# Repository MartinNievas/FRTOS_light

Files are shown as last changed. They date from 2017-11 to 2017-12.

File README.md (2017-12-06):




# Linterna frontal con diferentes modos de iluminación
La linterna cuenta con diferentes modos de iluminación. Es una versión simplificada inspirada en el modelo 
[NAO&reg;](https://www.petzl.com/US/en/Sport/PERFORMANCE-headlamps/NAO) de Petzl&reg;

## Modos de iluminación
* OFF (Default)
* ADAPTABLE
* AMPLIO
* CENTRADO
* AMPLIO + CENTRADO

##### Modo ADAPTABLE
La linterna regula la intensidad de los LED basada en la medición realizada por un fotodiodo. Los umbrales de cambio 
de intensidad controlan una máquina de estados, para evitar oscilaciones al cambiar entre modos.

## Circuito
La linterna se controla mediante una Arduino Pro-Mini y dos mosfet SMD (si2302) para controlar los LED. Cuenta con un botón en la placa 
para ir cambiando entre modos. 

## Alimentación
Utiliza dos bateras 18650 en serie. Esto  es así para alimentar la Arduino mediante el regulador provisto en la placa. 

## LEDs
La linterna utiliza dos LED. Uno de 3W para la iluminación centrada con un colimador de 16°, y un led de 5W para 
la iluminación amplia con un difusor de 60°

## Compilación y carga
El proyecto utiliza [platformio](http://platformio.org/). Para compilar y cargar en la Arduino hacer:
```
platofrmio run -t upload
```

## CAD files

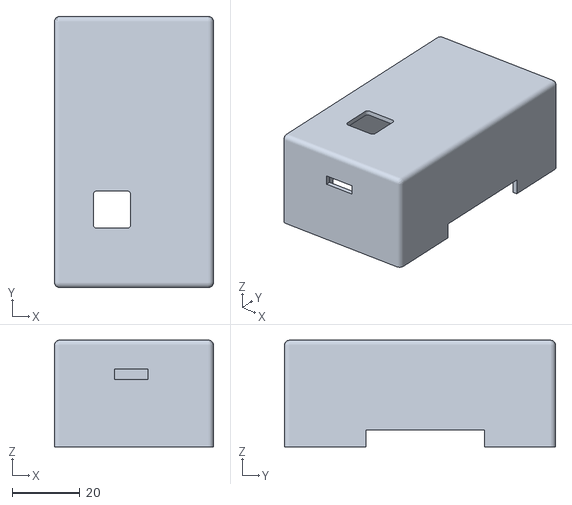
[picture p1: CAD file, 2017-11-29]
carcasa/tapa_porta_baterias.stl
47.0 x 80.0 x 31.5

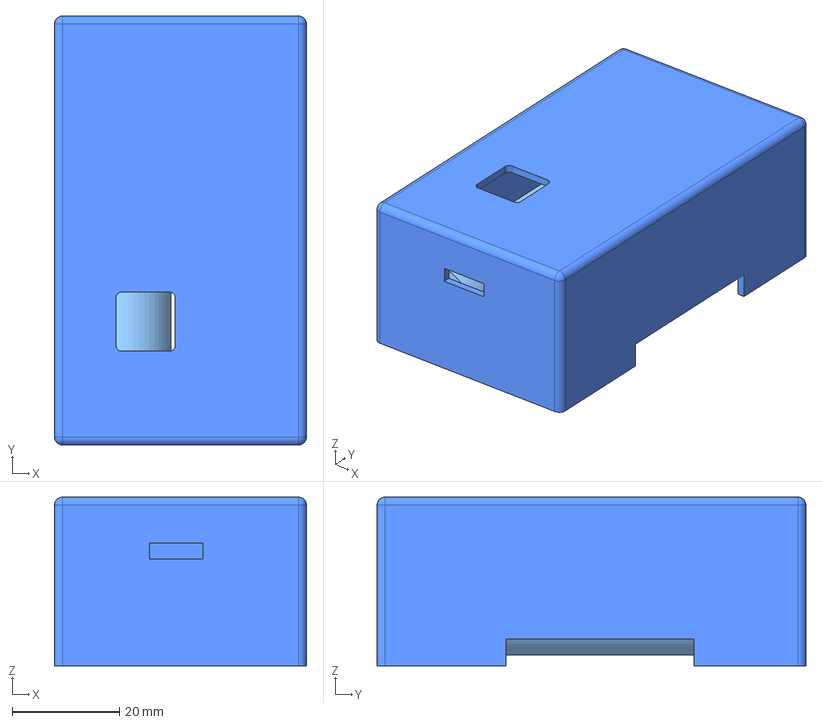
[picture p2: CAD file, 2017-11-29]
carcasa/porta_baterias_arduino.fcstd
47.0 x 80.0 x 31.5 mm

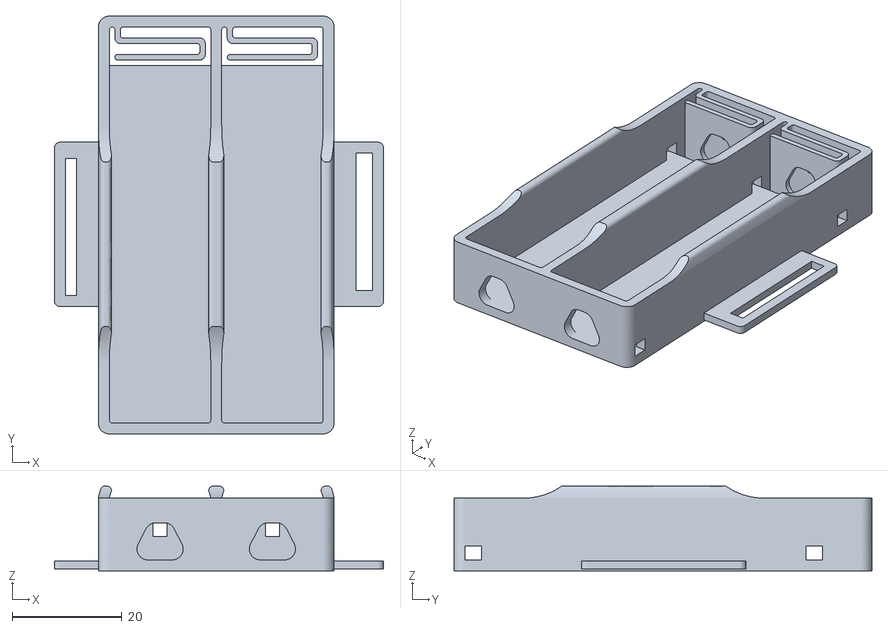
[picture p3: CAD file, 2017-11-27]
carcasa/base_porta_baterias.stl
60.0 x 76.2 x 15.5

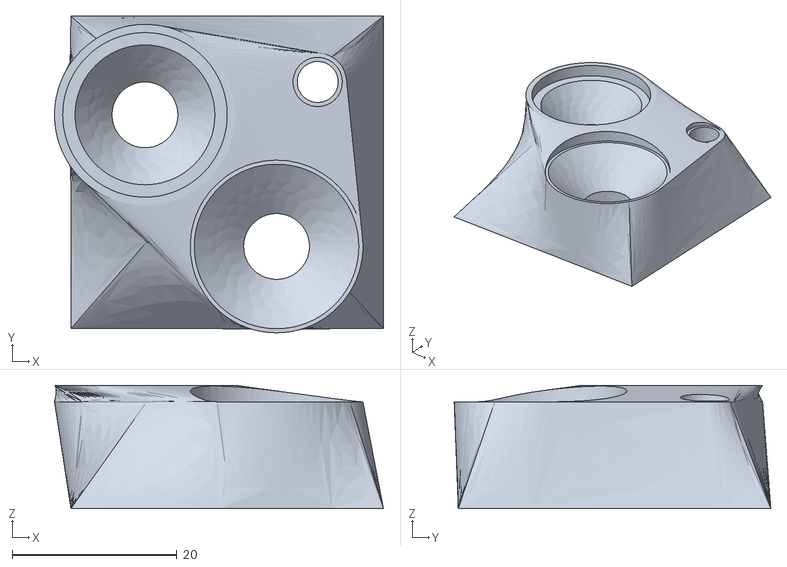
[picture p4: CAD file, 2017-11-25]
carcasa/frontal_V0_1.stl
40.0 x 38.5 x 15.0

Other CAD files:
carcasa/tapa_frontal.fcstd

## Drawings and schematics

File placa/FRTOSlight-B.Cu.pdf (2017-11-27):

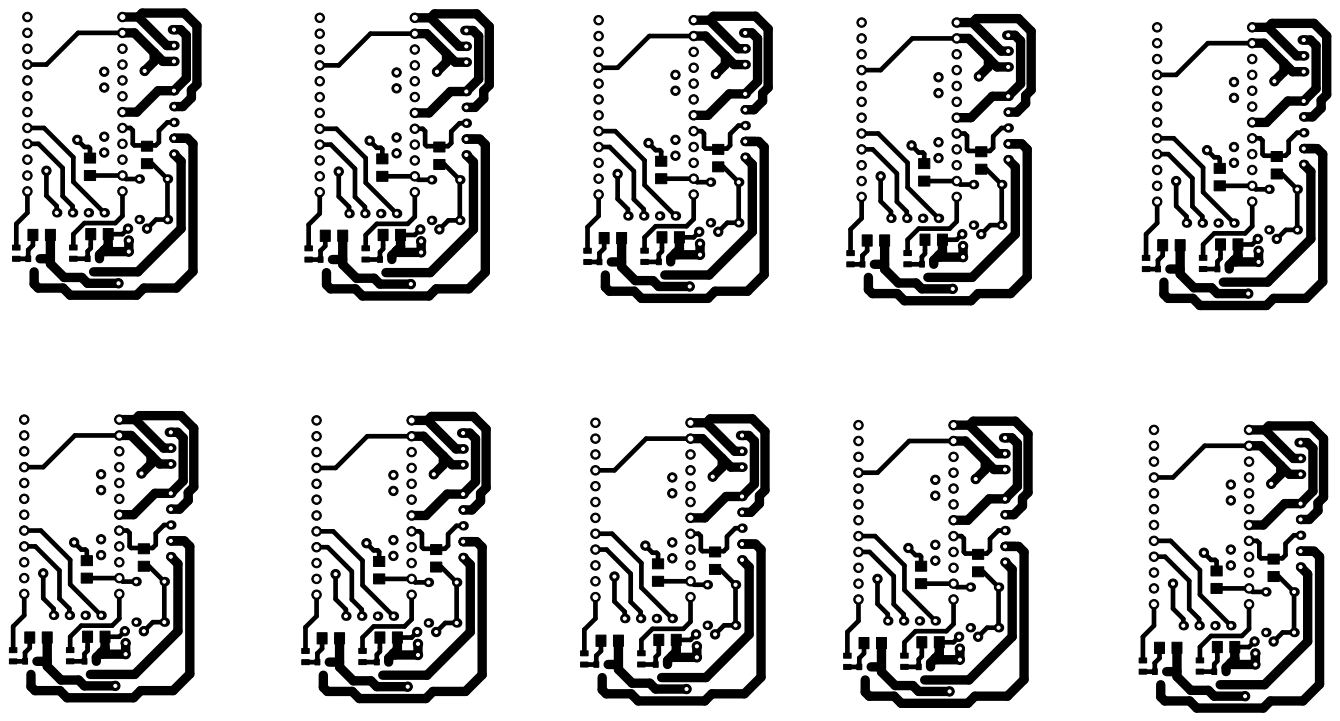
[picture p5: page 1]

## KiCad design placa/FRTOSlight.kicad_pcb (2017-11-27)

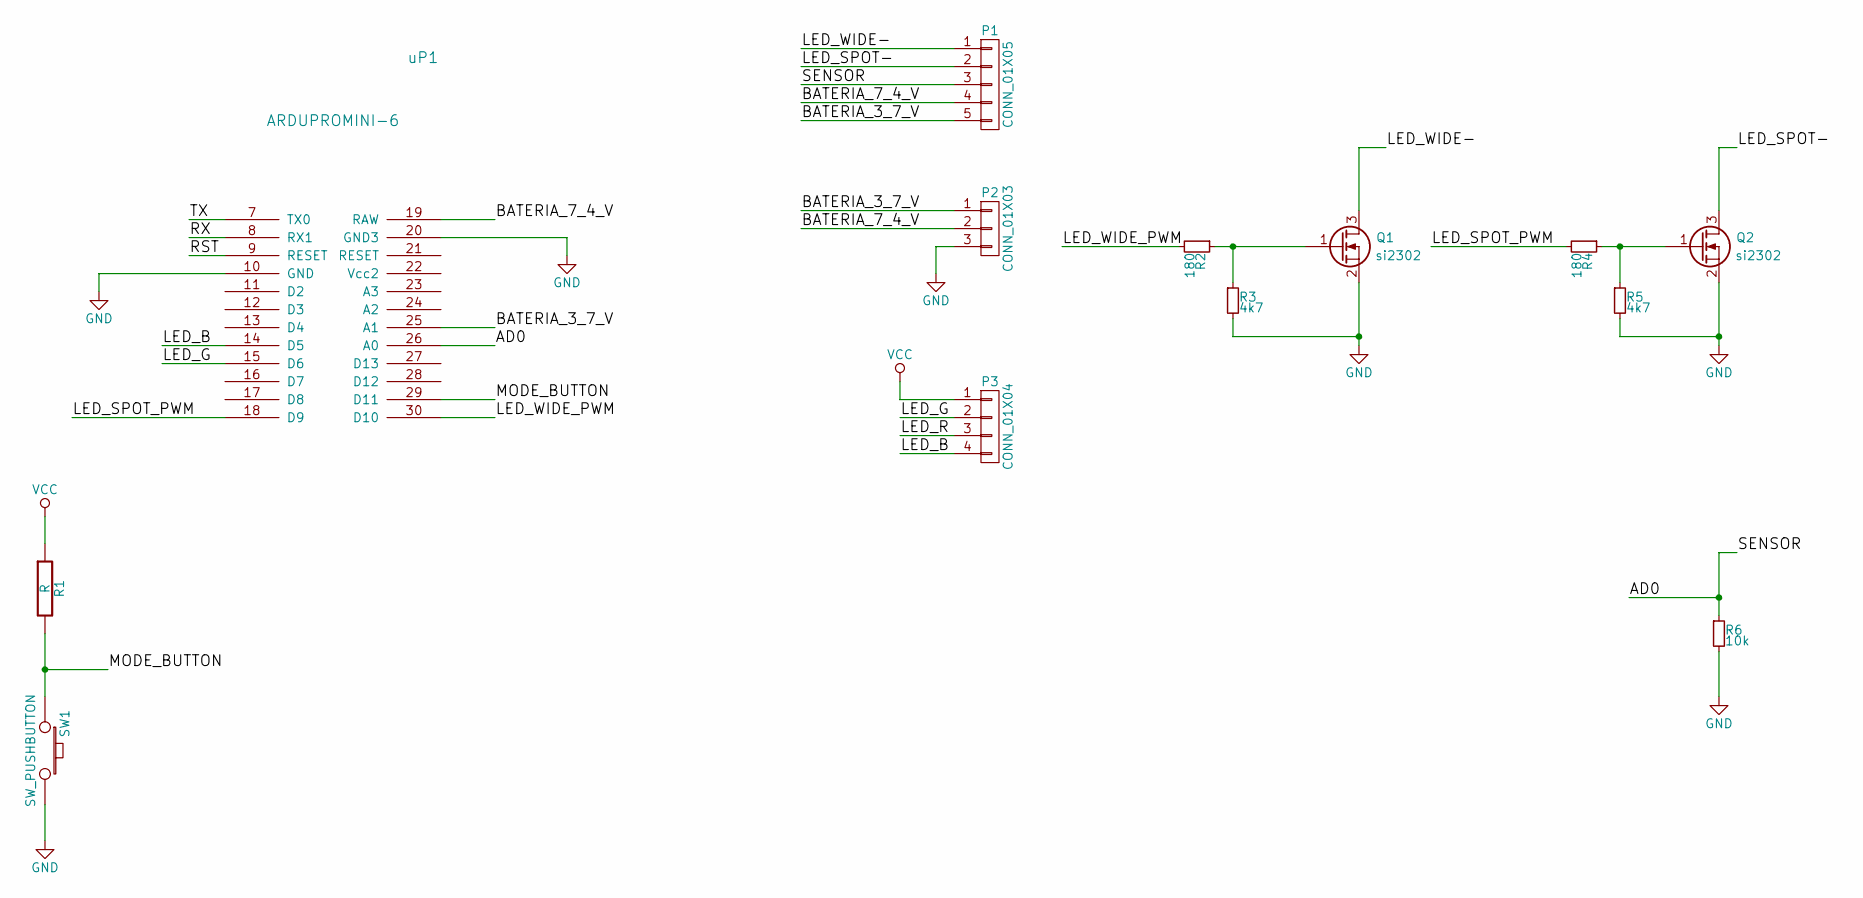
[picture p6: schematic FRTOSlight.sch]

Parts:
P1: CONN_01X05; 1X05
P2: CONN_01X03; 1X03
P3: CONN_01X04; 1X04
Q1, Q2: si2302; SOT23-3
R1: R; 1206
R2, R4: 180; 0805
R3, R5: 4k7; 1206
R6: 10k; 1206
SW1: SW_PUSHBUTTON; SW_PUSHBUTTON_PTH
uP1: ARDUPROMINI-6; ArduProMini-6

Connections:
/AD0: P1.3, R6.1, uP1.26 (A0)
/BATERIA_3_7_V: P1.5, P2.1, uP1.25 (A1)
/BATERIA_7_4_V: P1.4, P2.2, uP1.19 (RAW)
/LED_B: P3.4, uP1.14 (D5)
/LED_G: P3.2, uP1.15 (D6)
/LED_R: P3.3
/LED_SPOT-: P1.2, Q2.3 (D)
/LED_SPOT_PWM: R4.2, uP1.18 (D9)
/LED_WIDE-: P1.1, Q1.3 (D)
/LED_WIDE_PWM: R2.2, uP1.30 (D10)
/MODE_BUTTON: R1.2, SW1.1, uP1.29 (D11)
/RST: uP1.9 (RESET)
/RX: uP1.8 (RX1)
/TX: uP1.7 (TX0)
GND: P2.3, Q1.2 (S), Q2.2 (S), R3.2, R5.2, R6.2, SW1.2, uP1.10 (GND), uP1.20 (GND3)
unnamed: Q1.1 (G), R2.1, R3.1
unnamed: Q2.1 (G), R4.1, R5.1
VCC: P3.1, R1.1

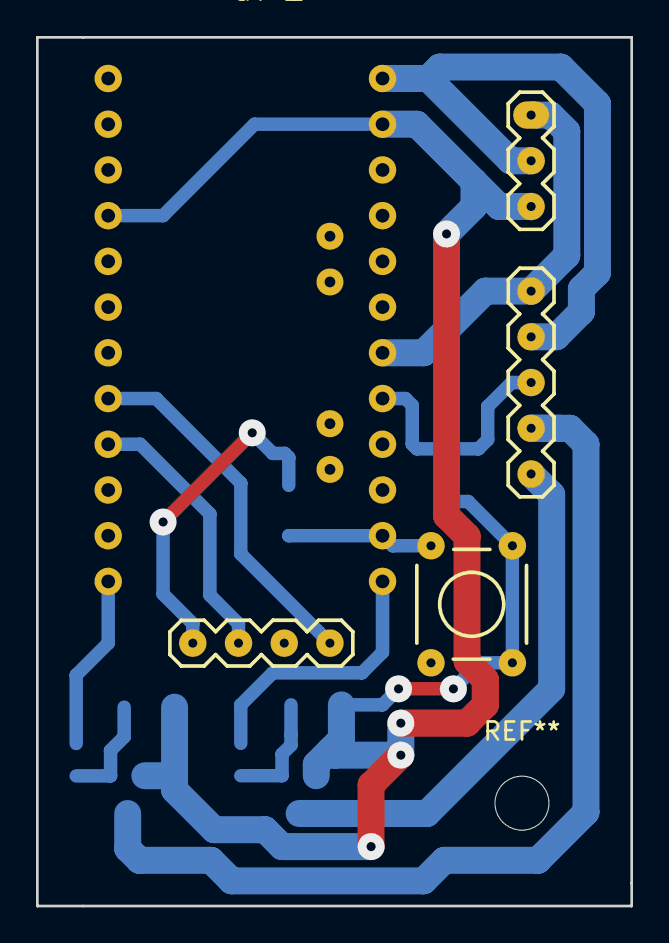
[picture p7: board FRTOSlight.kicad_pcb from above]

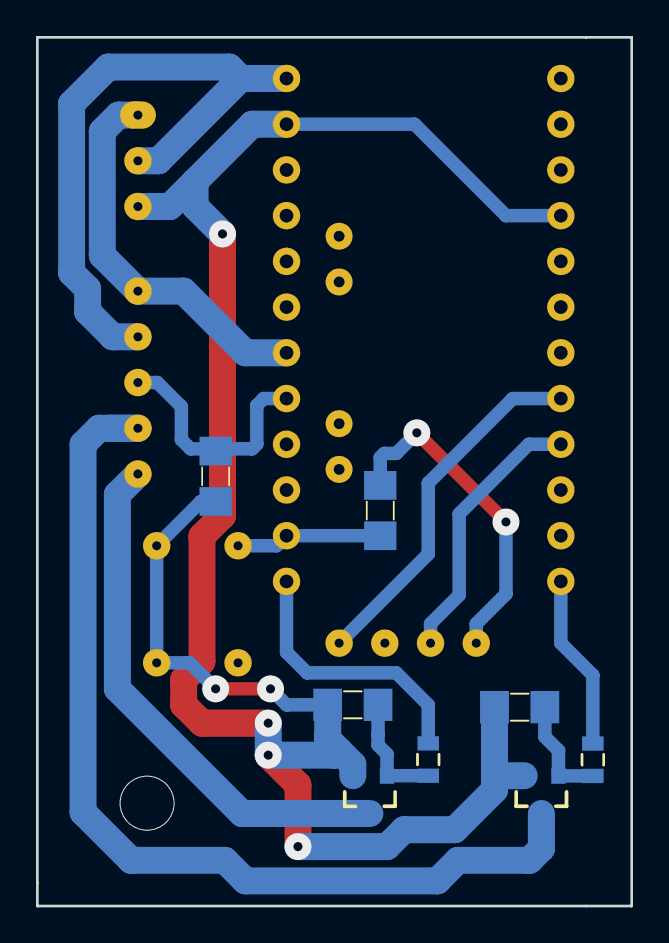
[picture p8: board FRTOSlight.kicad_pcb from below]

Board: 2 copper layers, 33.0 x 48.3 mm, 13 parts (8 on the bottom side), 14 nets.

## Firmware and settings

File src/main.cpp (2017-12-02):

#include <Arduino.h>
#include <Arduino_FreeRTOS.h>
#include <functions.h>
#include <configurations.h>

#define NZEROS 4
#define NPOLES 4
#define GAIN   1.509971716e+00

void TaskControlLightMode( void *pvParameters );
void TaskReadModeButton( void *pvParameters );
void TaskReadLightSensor( void *pvParameters );
void TaskBlink( void *pvParameters );

int light_mode = LIGHT_OFF;
int blink_mode = BLINK_OFF;
int press_duration = 0;

int intensity_mode = MODO_INTENSIDAD_NORMAL;

int short_press_flag = 0;
int blink_counter = 0;

int light_sensor_read = 0;
int light_sensor_read2 = 0;
int light_sensor_normalized_mapped = 0;
float light_sensor_filtered = 0;
float light_sensor_filtered_mapped = 0;

int battery_3_7_voltage = 0;


void setup() {
  
  Serial.begin(9600);
  
  /* Configuración de los pines de entrada y salida */
  pinMode(MODE_BUTTON, INPUT);
  pinMode(LED_PIN_FOCUS, OUTPUT);
  pinMode(LED_PIN_WIDE, OUTPUT);
  pinMode(LED_PIN_BATTERY_RED, OUTPUT);
  pinMode(LED_PIN_BATTERY_YELLOW, OUTPUT);
  pinMode(LED_PIN_BATTERY_GREEN, OUTPUT);

  /* Creación de las tareas */
  xTaskCreate(
    TaskControlLightMode
    ,  (const portCHAR *)"ControlLightMode"   
    ,  128  // Stack size
    ,  NULL
    ,  3    // Priority
    ,  NULL );

  xTaskCreate(
    TaskReadModeButton
    ,  (const portCHAR *) "ReadModeButton"
    ,  128   // Stack size
    ,  NULL
    ,  2     // Priority
    ,  NULL );

  xTaskCreate(
    TaskReadLightSensor
    ,  (const portCHAR *) "ReadLightSensor"
    ,  128  // Stack size
    ,  NULL
    ,  2    // Priority
    ,  NULL );

  xTaskCreate(
    TaskBlink
    ,  (const portCHAR *)"Blink"   
    ,  128  // Stack size
    ,  NULL
    ,  2    // Priority
    ,  NULL );


}

void loop()
{
  // Nada. La magia sucede en las tareas 
}

/* Tarea encargada de controlar la intensidad de los LEDs principales */
void TaskControlLightMode(void *pvParameters)  
{
  (void) pvParameters;
  
  for (;;) 
  {

    switch(light_mode)
     {
       case LIGHT_OFF:
         analogWrite(LED_PIN_FOCUS, 0);
         analogWrite(LED_PIN_WIDE, 0);
         blink_mode = BLINK_OFF;
         break;
       case LIGHT_ADAPTABLE:
         blink_mode = BLINK_BREATH;
          switch(intensity_mode)
          {
            case MODO_INTENSIDAD_CERCA:
              analogWrite(LED_PIN_FOCUS, PWM_CERCA );
              analogWrite(LED_PIN_WIDE, PWM_CERCA );
              break;
            case MODO_INTENSIDAD_NORMAL:
              analogWrite(LED_PIN_FOCUS, PWM_NORMAL );
              analogWrite(LED_PIN_WIDE, PWM_NORMAL );
              break;
            case MODO_INTENSIDAD_LEJOS:
              analogWrite(LED_PIN_FOCUS, PWM_LEJOS );
              analogWrite(LED_PIN_WIDE, PWM_LEJOS );
              break;
          }
         break;
       case LIGHT_WIDE:
         analogWrite(LED_PIN_WIDE, PWM_CERCA);
         analogWrite(LED_PIN_FOCUS, PWM_APAGADO);
         blink_mode = BLINK_SLOW;
         break;
       case LIGHT_FOCUS:
         analogWrite(LED_PIN_FOCUS, PWM_MAXIMO);
         analogWrite(LED_PIN_WIDE, PWM_APAGADO);
         blink_mode = BLINK_SLOW;
         break;
       case LIGHT_WIDE_AND_FOCUS:
         analogWrite(LED_PIN_FOCUS, PWM_LEJOS);
         analogWrite(LED_PIN_WIDE, PWM_LEJOS);
         blink_mode = BLINK_FAST;
         break;
       default:
         light_mode = LIGHT_OFF;
         break;
     }

    vTaskDelay( 100 / portTICK_PERIOD_MS ); 
  }
}

/* Tarea encargada de leer el botón de modo. 
 * Controla cuanto tiempo se mantuvo presionado el botón */
void TaskReadModeButton(void *pvParameters) 
{
  (void) pvParameters;
  
  pinMode(MODE_BUTTON, INPUT);

  for (;;)
  {
  if (!digitalRead(MODE_BUTTON))
  {
    press_duration++;
    if (press_duration == PRESS_DURATION_LONG)
    {
      light_mode = LIGHT_ADAPTABLE;
      short_press_flag = FALSE;
    }
    if(press_duration < PRESS_DURATION_SHORT)
    {
      short_press_flag = TRUE;
    }
  }
  else
  {
      if (short_press_flag == TRUE) 
      {
        if (light_mode <  CONT_MODE_LIGHT)
        {
          light_mode++;
        }
        else
        {
          light_mode = LIGHT_ADAPTABLE;  
        }
      }
      press_duration = 0;
      short_press_flag = FALSE;
  }
  

  check_battery_level(battery_3_7_voltage);

    vTaskDelay(1);
  }
}

/* Tarea encargada de leer el fototransistor. 
 * Además actualiza el estado que controla la intensidad de los LED  */
void TaskReadLightSensor(void *pvParameters) 
{
  (void) pvParameters;

  pinMode(7, INPUT);
  pinMode(8, INPUT);
  
  for (;;)
  {


    light_sensor_read = analogRead(A0);

    battery_3_7_voltage = analogRead(A1);

    /* Controlador de la máquina de estados para el control de la intensidad */
    check_brightness_level( light_sensor_read);

    vTaskDelay( 90 / portTICK_PERIOD_MS ); 
  }
}

/* Tarea encargada de realizar el parpadeo del led RGB */
void TaskBlink(void *pvParameters)  // This is a task.
{
  (void) pvParameters;
  
  pinMode(LED_PIN_BLINK_BLUE, OUTPUT);
  pinMode(LED_PIN_BLINK_GREEN, OUTPUT);

  for (;;) 
  {
    switch(blink_mode)
    {
      case BLINK_OFF:
        analogWrite(LED_PIN_BLINK_BLUE, PWM_BLINK_OFF);
        analogWrite(LED_PIN_BLINK_GREEN, PWM_BLINK_OFF);
        break;
      case BLINK_SLOW:
        blink_counter++;
        if (blink_counter < BLINK_DURATION_SLOW) 
        {
          analogWrite(LED_PIN_BLINK_BLUE, PWM_BLINK_OFF);
          analogWrite(LED_PIN_BLINK_GREEN, PWM_BLINK_OFF);
        }
        if ( blink_counter == BLINK_DURATION_SLOW ) 
        {
          analogWrite(LED_PIN_BLINK_BLUE, PWM_BLINK_ON);
          analogWrite(LED_PIN_BLINK_GREEN, PWM_BLINK_ON);
        }
        if ( blink_counter > BLINK_DURATION_SLOW ) 
        {
          blink_counter = 0;
        }
        break;
      case BLINK_FAST:
        blink_counter++;
        if (blink_counter < BLINK_DURATION_FAST) 
        {
          analogWrite(LED_PIN_BLINK_BLUE, PWM_BLINK_OFF);
          analogWrite(LED_PIN_BLINK_GREEN, PWM_BLINK_OFF);
        }
        if ( blink_counter == BLINK_DURATION_FAST ) 
        {
          analogWrite(LED_PIN_BLINK_BLUE, PWM_BLINK_OFF);
          analogWrite(LED_PIN_BLINK_GREEN, PWM_BLINK_OFF);
        }
        if ( blink_counter > BLINK_DURATION_FAST ) 
        {
          blink_counter = 0;
        }
        break;
      case BLINK_BREATH:
        blink_counter++;
        if ( blink_counter <= 127 ) 
        {
          analogWrite(LED_PIN_BLINK_BLUE, 512 - blink_counter*2 );
          analogWrite(LED_PIN_BLINK_GREEN, 512 - blink_counter*2 );

        }
        if ( blink_counter > 127 && blink_counter < 255 ) 
        {
          analogWrite(LED_PIN_BLINK_BLUE,blink_counter*2);
          analogWrite(LED_PIN_BLINK_GREEN,blink_counter*2);
        }
        if ( blink_counter == 255 ) 
        {
          blink_counter = 0;
        }

        break;
    }

    vTaskDelay( 25 / portTICK_PERIOD_MS ); 
  }
}

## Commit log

2017-11-22 Boton para cambiar de modo funcionando Intensidad de la linterna cambia con la luz ambiente
2017-11-25 Versión 0.1 de la carcasa. Cuando la imprimí le faltó un poco mas de altura para que quedara bien el colimador, habría que calibrarlo para cada versión :\
    [frontal_V0_1.stl, tapa_frontal.fcstd]
2017-11-25 Función para el blink en rGB
2017-11-25 Blink BREATH funcionando. El led que tengo es anodo común, por eso está invertido el ciclo de PWM
2017-11-27 Carcasa posterior. Dos partes, el porta baterías y la tapa
    [base_porta_baterias.stl, porta_baterias_arduino.fcstd, tapa_porta_baterias.stl]
2017-11-27 PCB para la arduino pro mini con los driver de los LEDs y el botón incluido
    [FRTOSlight.kicad_pcb, FRTOSlight.sch]
2017-11-27 Función de realimentación de la intensidad lumínica frontal, con un filtro pasabajos incluído para que los cambios no sean tan abruptos
2017-11-29 Modificaciones en el botón de cambio de modo
    [porta_baterias_arduino.fcstd, tapa_porta_baterias.stl]
2017-12-02 Configuración para el modo de iluminación automático
2017-12-02 Ordenando el código. Versión 1.0 estable

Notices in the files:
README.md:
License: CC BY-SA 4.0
